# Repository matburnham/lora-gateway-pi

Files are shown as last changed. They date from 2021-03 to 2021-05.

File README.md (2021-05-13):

# Raspberry Pi LoRa gateway HAT for RFM9x, DRF1278F and XL1278-SMT boards

A somewhat 'universal' LoRa gateway HAT for RFM9x, DRF1278F and XL1278-SMT boards loosely based upon [Raspberry Pi+ LoRa(TM) Expansion Board](https://store.uputronics.com/index.php?route=product/product&path=61&product_id=68) and designed for the [PiInTheSky/lora-gateway](https://github.com/PiInTheSky/lora-gateway) code.

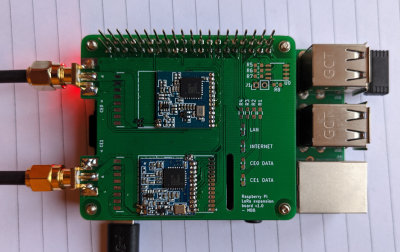
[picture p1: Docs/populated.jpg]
Populated board


_Populated module installed on a Rapsberry Pi 2_

# Configuration

The board is designed for use with [PiInTheSky/lora-gateway](https://github.com/PiInTheSky/lora-gateway). See [Software/gateway-sample.txt](Software/gateway-sample.txt) for a starting point configuration. Note DIO5_0=1 must be set as unlike the rest it is not the default. WiringPi seems to rather unhelpfully offer a third 'standard' for Rapsberry Pi pins. [WiringPi GPIO pinout](https://pinout.xyz/pinout/wiringpi_gpio_pinout) is good reference showing equivalent BCM, WiringPi and expansion header pin numbers.

PITS lora-gateway UI

# Testing

Only the configuration pictured above (DRF1278F in CE0 and XL1278-SMT in CE1) has been tested. Neither the indicator LEDs nor the Pi hat EEPROM have been populated and tested yet.

Note [PCB layout issues with v1.0](https://github.com/matburnham/lora-gateway-pi/issues/1), notably that the XL1278-SMT footprint is slightly out as the through-holes don't line up. Surface mounting the module works perfectly fine.

# Module identification

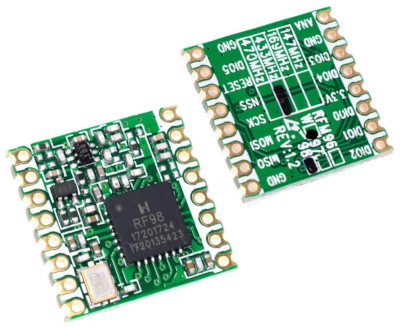
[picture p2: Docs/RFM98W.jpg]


_HOPERF RFM98W_

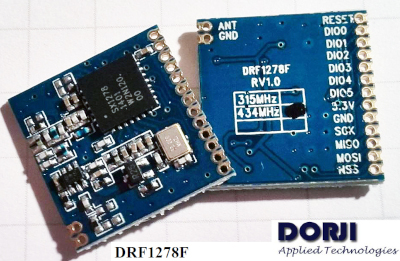
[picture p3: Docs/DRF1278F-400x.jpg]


_Dorji DRF1287F_

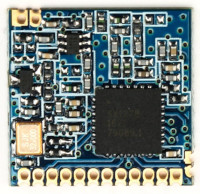
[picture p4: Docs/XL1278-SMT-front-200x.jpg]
XL1278-SMT-front
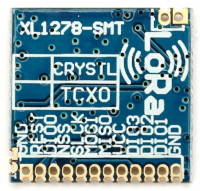
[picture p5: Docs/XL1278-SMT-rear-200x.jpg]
XL1278-SMT-back
 

_HR-WT XL1278-SMT_

Note: while the DRF1278F and XL1278-SMT boards look similar, their pinouts are significantly different.

## Confusion

There is a lot of confusion between Ebay and AliExpress sellers alike. One ebay seller even showing photos of both types of boards on the same listing. So check carefully, or use what you're given with this either/or breakout.

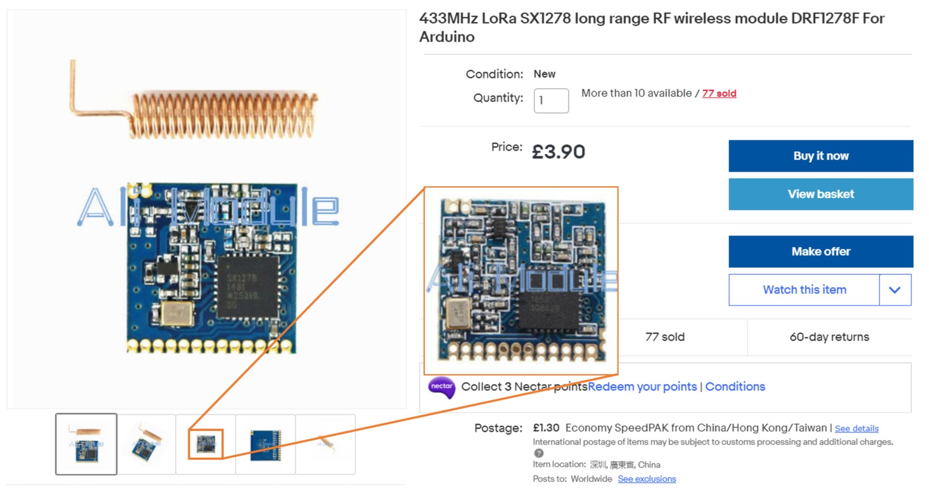
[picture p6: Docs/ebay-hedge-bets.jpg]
Ebay screenshot


# Documentation

CI/CD documentation generation 

TODO: links to generated documentation, etc.

## Version 1.0

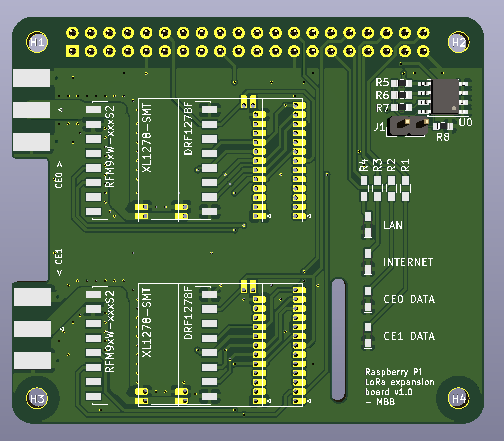
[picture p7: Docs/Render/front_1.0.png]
Front render

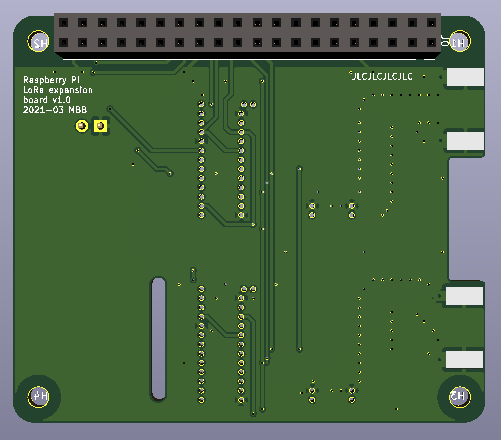
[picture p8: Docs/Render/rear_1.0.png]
Rear render


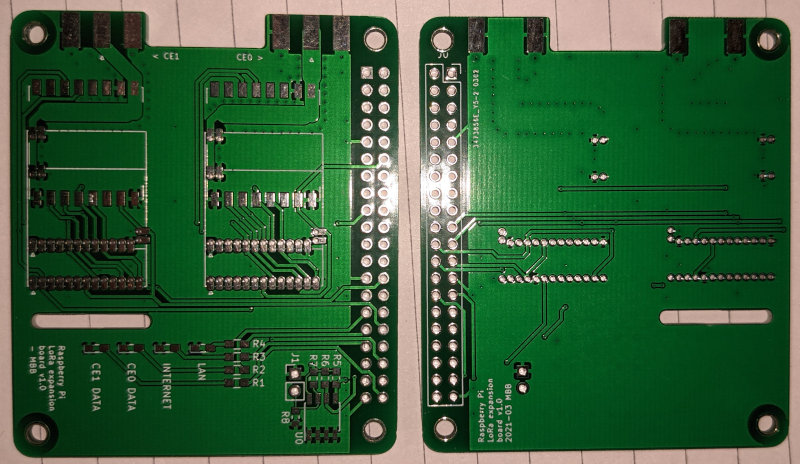
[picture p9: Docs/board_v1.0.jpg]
Unpopulated board v1.0


## Version 1.1

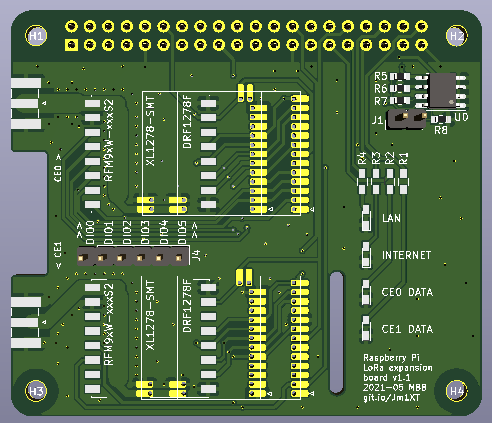
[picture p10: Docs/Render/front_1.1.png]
Front render

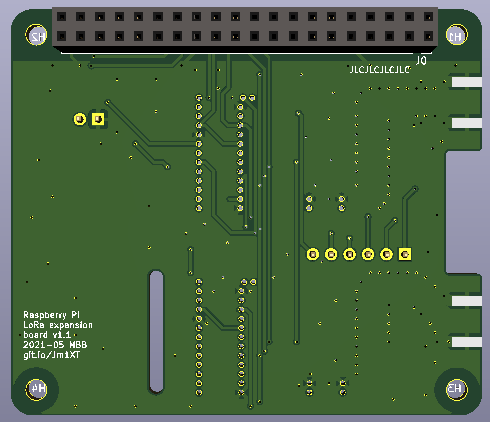
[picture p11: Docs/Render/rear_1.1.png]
Rear render


# Libraries

* KiCad symbol and footprint libraries for DRF1278F and XL1278-SMT for KiCad are at [kicad-libs](https://github.com/matburnham/kicad-libs)

# References

* Inspired by Uputronics' [Raspberry Pi+ LoRa(TM) Expansion Board](https://store.uputronics.com/index.php?route=product/product&path=61&product_id=68)

* [Dorji DRF1278F datasheet](http://www.dorji.com/docs/data/DRF1278F.pdf) | [respository copy](Docs/DRF1278F.pdf)
* Closest information to a [XL1278-SMT datasheet](http://www.hr-wt.com/html_products/XL1278-SMT-59.html) | [respository screenshot](Docs/screencapture-hr-wt-html-products-XL1278-SMT-59-html-2021-02-26-15_49_33.png)

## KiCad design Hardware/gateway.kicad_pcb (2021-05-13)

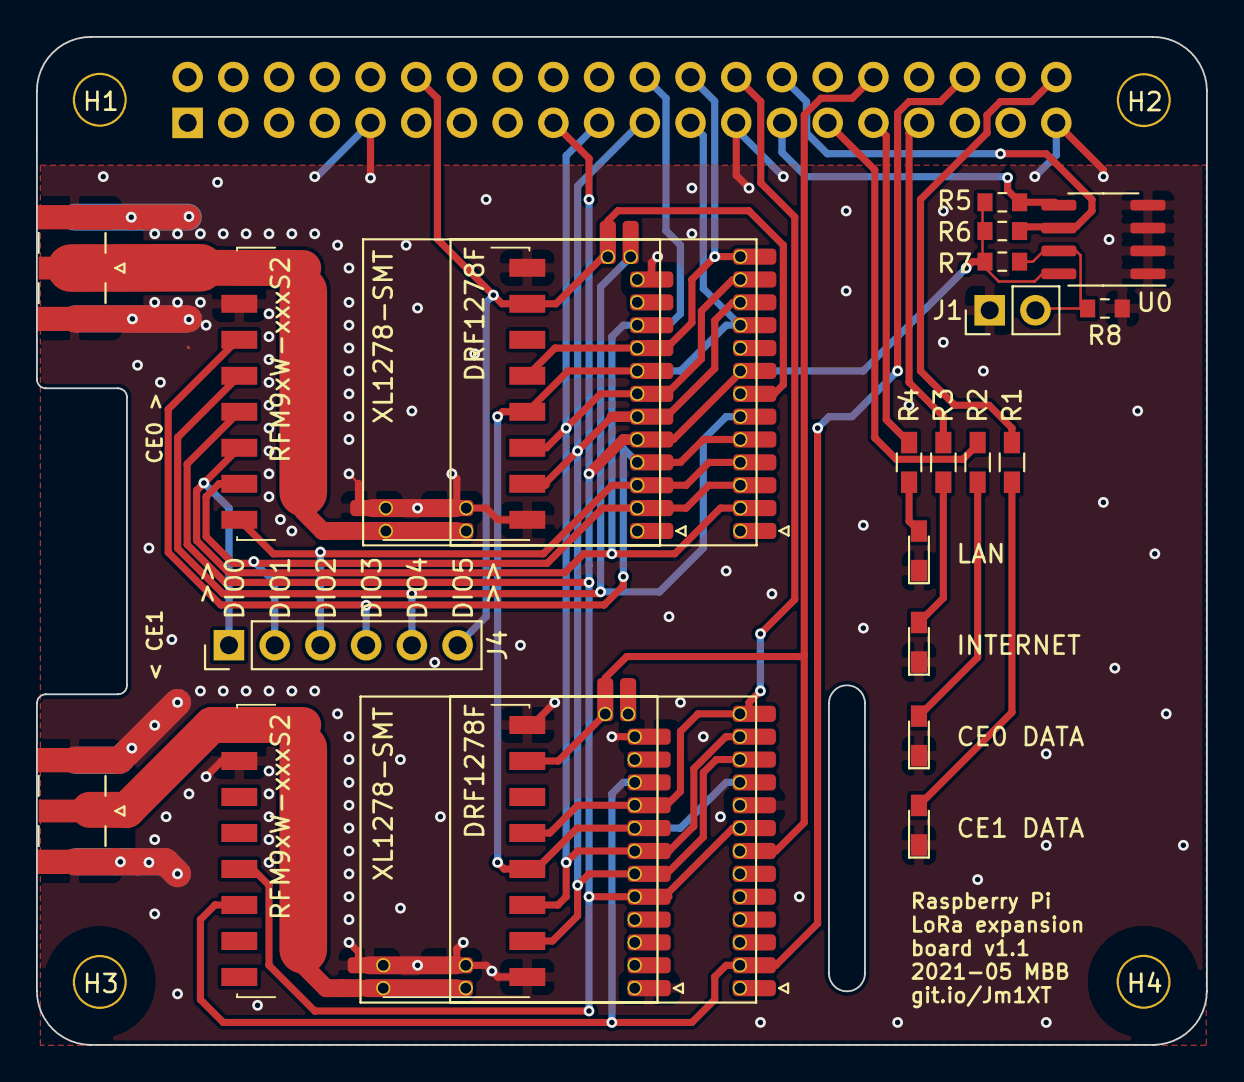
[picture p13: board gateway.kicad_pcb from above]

Board: 2 copper layers, 65.0 x 56.0 mm, 28 parts (1 on the bottom side), 28 nets.

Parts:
D1, D2, D3, D4: LED; LED_0603_HandSoldering
H1, H2, H3, H4: 3mm_Mounting_Hole; NPTH_3mm_ID
J0: Raspberry_Pi_2_3_40HAT; PinSocket_2x20_P2.54mm_Vertical
J1: CONN_01X02; PinHeader_1x02_P2.54mm_Vertical
J2, J3: Conn_Coaxial; SMA_Samtec_SMA-J-P-X-ST-EM1_EdgeMount
J4: Conn_01x06; PinHeader_1x06_P2.54mm_Vertical
R1, R2, R3, R4: 330; R_0603_HandSoldering
R5, R6: 3.9K; R_0603_1608Metric_Pad0.84x1.00mm_HandSolder
R7: 10K; R_0603_1608Metric_Pad0.84x1.00mm_HandSolder
R8: DNP; R_0603_1608Metric_Pad0.84x1.00mm_HandSolder
U0: CAT24C32; SOIC-8_3.9x4.9mm_P1.27mm
U0a1, U1a1: DRF1278F
U0b1, U1b1: XL1278-SMT
U0c1, U1c1: RFM9xW-xxxS2; Hopref_RFM9XW_SMD

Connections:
0_ANT: J2.1, U0a1.15, U0b1.16, U0c1.9
0_DATA_LED: J0.29, R2.1
0_DIO0: J0.22, J4.1, U0a1.2, U0b1.10, U0c1.14
0_DIO1: J4.2, U0a1.3, U0b1.2, U0c1.15
0_DIO2: J4.3, U0a1.4, U0b1.3, U0c1.16
0_DIO3: J4.4, U0a1.5, U0b1.4, U0c1.11
0_DIO4: J4.5, U0a1.6, U0b1.13, U0c1.12
0_DIO5: J0.12, J4.6, U0a1.7, U0b1.14, U0c1.7
0_NSS: J0.24, U0a1.13, U0b1.9, U0c1.5
1_ANT: J3.1, U1a1.15, U1b1.16, U1c1.9
1_DATA_LED: J0.40, R1.1
1_DIO0: J0.36, U1a1.2, U1b1.10, U1c1.14
1_DIO5: J0.32, U1a1.7, U1b1.14, U1c1.7
1_NSS: J0.26, U1a1.13, U1b1.9, U1c1.5
/ID_SC_EEPROM: J0.28, R6.2, U0.6
/ID_SD_EEPROM: J0.27, R5.2, U0.5
GND: D1.1, D2.1, D3.1, D4.1, J0.9, J0.25, J0.39, J1.1, J2.2, J3.2, R8.2, U0.1, U0.2, U0.3, U0.4, U0a1.9, U0a1.14, U0b1.1, U0b1.12, U0b1.15, U0c1.1, U0c1.8, U0c1.10, U1a1.9, U1a1.14, U1b1.1, U1b1.12, U1b1.15, U1c1.1, U1c1.8, U1c1.10
INTERNET: J0.33, R3.1
LAN: J0.31, R4.1
MISO: J0.21, U0a1.11, U0b1.6, U0c1.2, U1a1.11, U1b1.6, U1c1.2
MOSI: J0.19, U0a1.12, U0b1.7, U0c1.3, U1a1.12, U1b1.7, U1c1.3
unnamed: D1.2, R1.2
unnamed: D2.2, R2.2
unnamed: D3.2, R3.2
unnamed: D4.2, R4.2
unnamed: J1.2, R7.2, R8.1, U0.7
SCK: J0.23, U0a1.10, U0b1.8, U0c1.4, U1a1.10, U1b1.8, U1c1.4
VCC: J0.17, R5.1, R6.1, R7.1, U0.8, U0a1.8, U0b1.5, U0c1.13, U1a1.8, U1b1.5, U1c1.13

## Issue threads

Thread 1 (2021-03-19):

PCB layout issues

matburnham, 2021-03-19:
Issues noted from first batch of PCBs from JLCPCB:

- Chip identifier silkscreen text missing - was it on the right layer, was the same on another layer?
- Raspberry Pi 40-pin header silkscreen is on the wrong side. Luckily, only the silkscreen was flipped.
- Should add a few more vias to connect ground planes

Also note matburnham/kicad-libs#1 footprint issues which should be fixed and pulled in.

matburnham, 2021-03-19:
Seems some of the text didn't make the silkscreen gerber and I didn't spot it:

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

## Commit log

2021-03-01 Initial import of handiwork.
    [gateway.kicad_pcb, gateway.sch]
2021-03-01 Fix antenna ground connections
    [gateway.kicad_pcb]
2021-03-01 Fix more grounds.
    [gateway.kicad_pcb]
2021-03-01 Final fix.
    [gateway.kicad_pcb]
2021-03-19 Image of actual board.
2021-03-20 Sample config file.
2021-03-20 Populated board
2021-05-11 Adjust footprints and add vias as per #1 Updated XL1278-SMT and DRF1278F footprints from matburnham/kicad-libs#1. Changed SMA footprint. Added some more GND vias.
    [gateway.kicad_pcb]
2021-05-13 Tweaks for #1.
    [gateway.kicad_pcb, gateway.sch]
2021-05-13 Fix #2 Adds a breakout for CE0, but not for CE1 as there's insufficient space.
    [gateway.kicad_pcb, gateway.sch]
